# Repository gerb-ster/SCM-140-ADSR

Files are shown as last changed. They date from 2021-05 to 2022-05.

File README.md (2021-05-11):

# SCM 140 ADSR

This module is a straight up clone of the ADSR module found it the famous Roland System-100m modular synthesizer from the ’70’s. It consists of 2 identical ADSR generators with a positive and a negative output. I’ve build this some years ago, there are other simpler designs out there, however, it was a really good learning experience.

## Status: Finished

- done: first schematic & board design
- done: breadboard and test
- done: design frontpanel
- done: order PCB and build prototype

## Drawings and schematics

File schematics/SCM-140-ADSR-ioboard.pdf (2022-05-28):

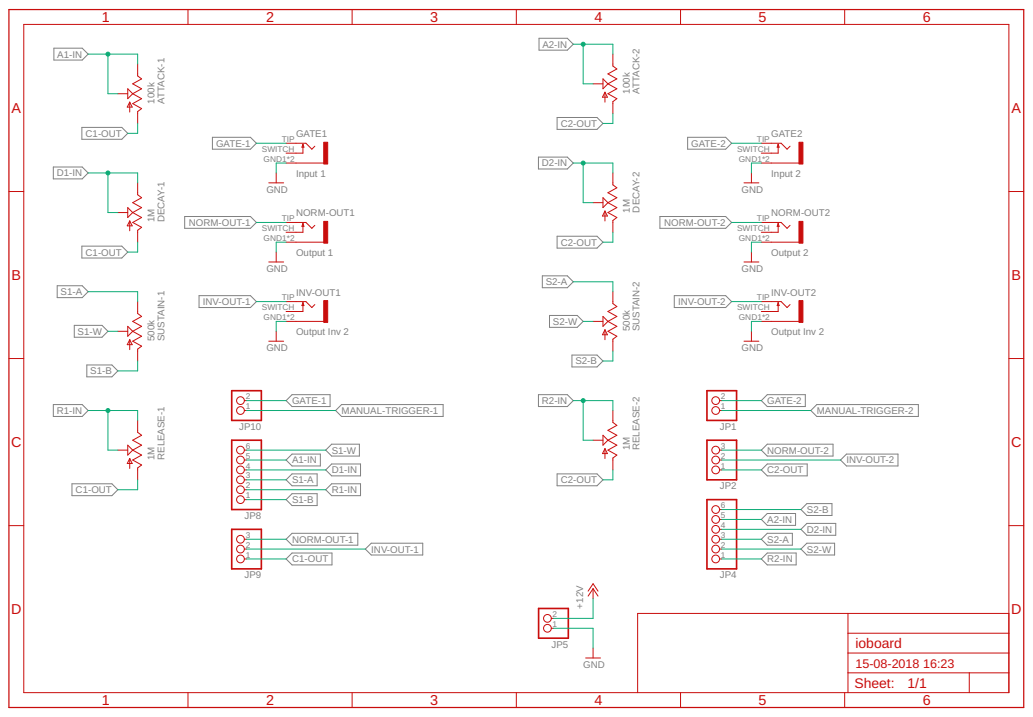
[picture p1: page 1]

100k 1M 500k 1M 100k 1M 500k 1M Input 1 Output 1 Output Inv 2 Input 2 Output 2 Output Inv 2 +12V GND GND GND GND GND GND GND ATTACK-1 DECAY-1 SUSTAIN-1 RELEASE-1 ATTACK-2 DECAY-2 SUSTAIN-2 RELEASE-2 TIP SWITCH GND1*2GATE1 TIP SWITCH GND1*2 NORM-OUT1 TIP SWITCH GND1*2 INV-OUT1 TIP SWITCH GND1*2GATE2 TIP SWITCH GND1*2 NORM-OUT2 TIP SWITCH GND1*2 INV-OUT2 123456JP8 123JP9 12 JP10 123456JP4 12JP1 123JP2 12JP5 MANUAL-TRIGGER-1 S1-B S1-B A1-IN A1-IN S1-W S1-W C1-OUT C1-OUT C1-OUT C1-OUT S1-A S1-A D1-IN D1-IN R1-IN R1-IN GATE-1 GATE-1 NORM-OUT-1 NORM-OUT-1 INV-OUT-1 INV-OUT-1 MANUAL-TRIGGER-2 S2-B S2-B A2-IN A2-IN S2-W S2-W C2-OUT C2-OUT C2-OUT C2-OUT S2-A S2-A R2-IN R2-IN D2-IN D2-IN GATE-2 GATE-2 NORM-OUT-2 NORM-OUT-2 INV-OUT-2 INV-OUT-2 Sheet: ABCD 1 2 3 4 5 6 ABCD 1 2 3 4 5 6 ioboard 15-08-2018 16:23 1/1

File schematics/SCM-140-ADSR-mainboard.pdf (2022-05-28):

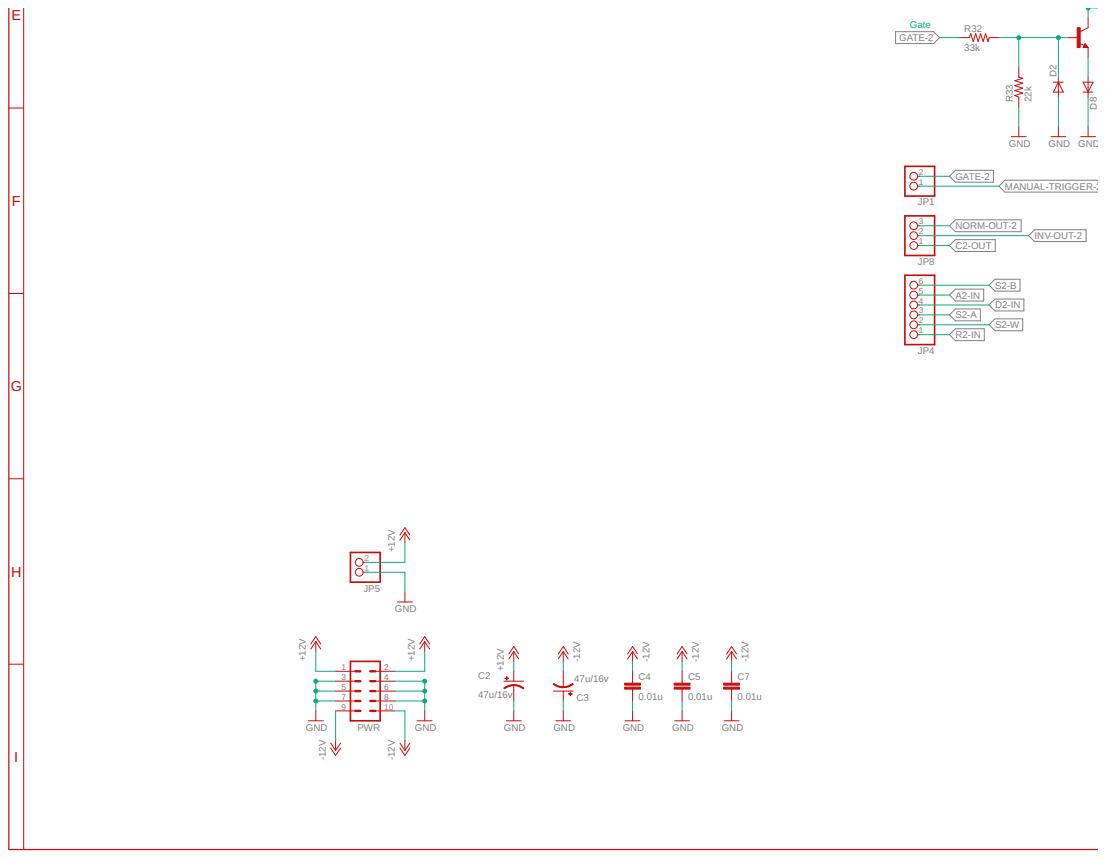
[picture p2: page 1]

-12V -12V GND GND +12V +12V 47u/16v 47u/16v +12V-12V GND GND GND -12V 0.01u 0.01u -12V GND 33k 22k GND GND GND +12V GND 0.01u GND -12V 1 2 3 4 5 6 7 8 9 10 PWR C2 C3 C4 C5 R32 R33 D2 D8 123456JP4 12JP5 12JP1 123JP8 C7 MANUAL-TRIGGER-2 S2-B A2-IN S2-W C2-OUT S2-A R2-IN D2-IN GATE-2 GATE-2 NORM-OUT-2 INV-OUT-2 EFGHI Gate

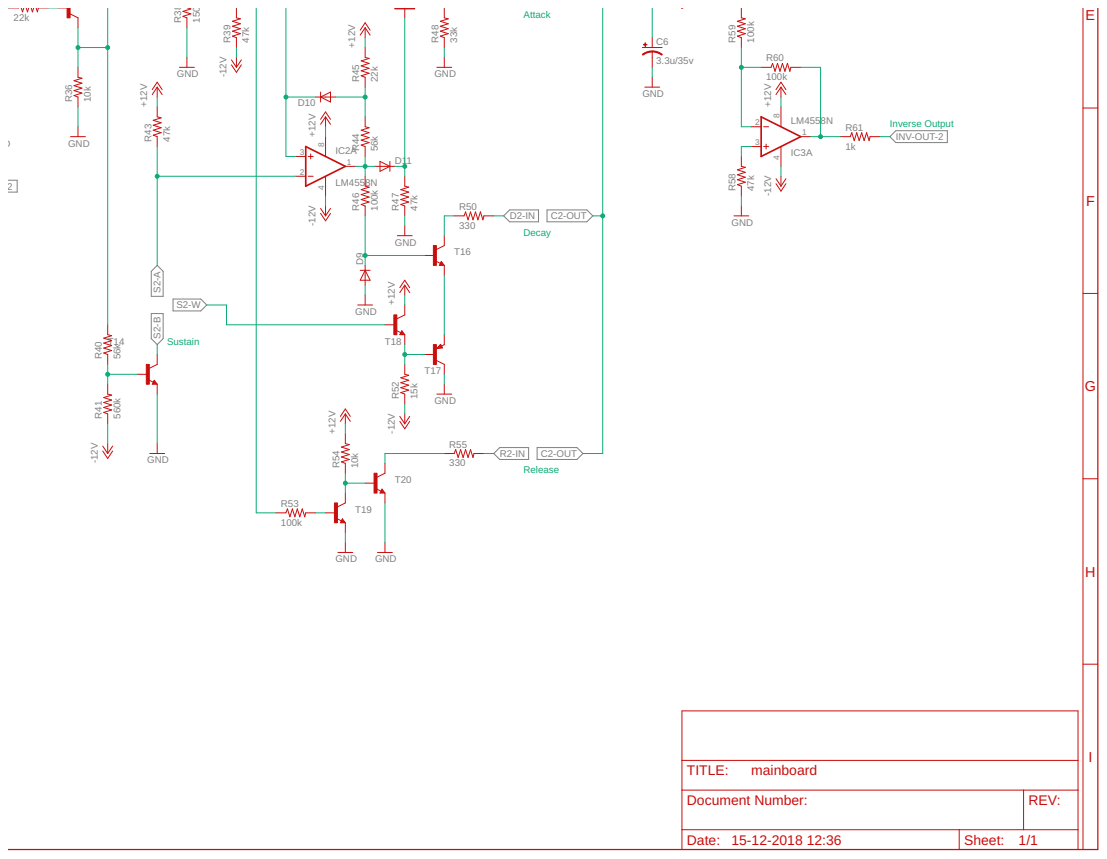
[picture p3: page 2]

Document Number: | REV:

Date: 15-12-2018 12:36 | Sheet: 1/1

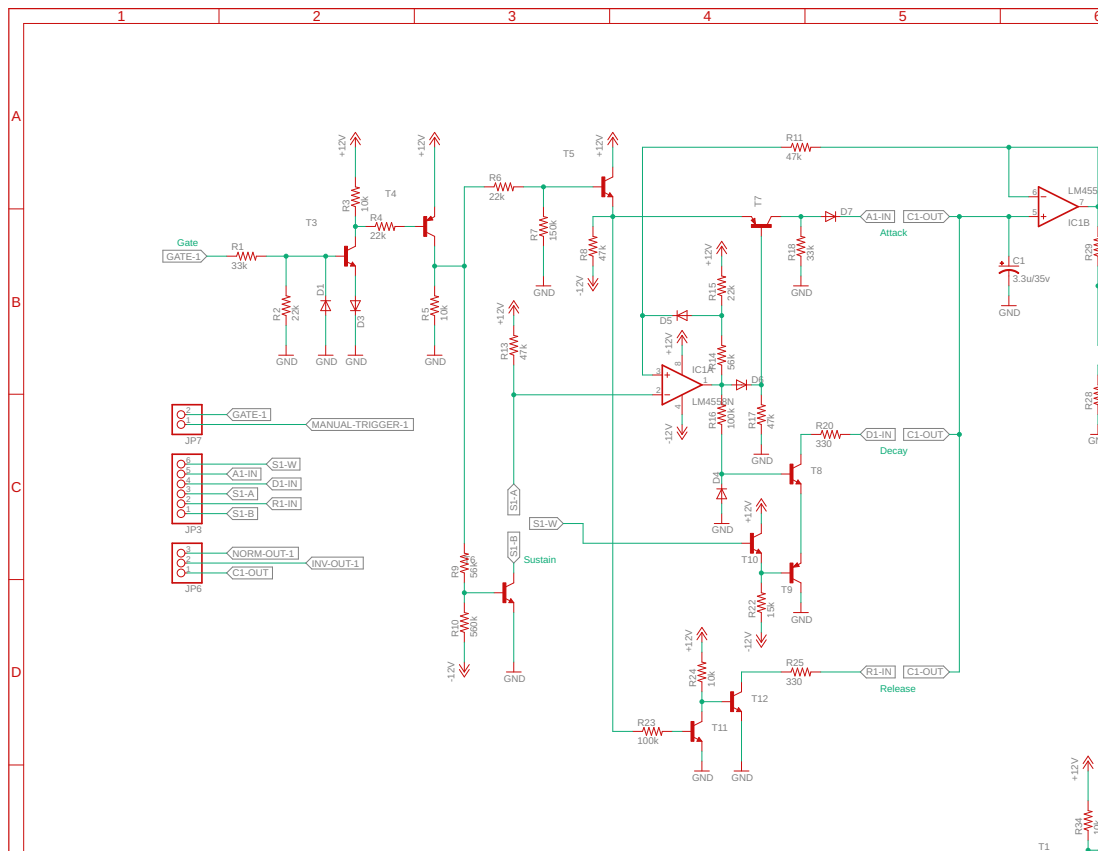
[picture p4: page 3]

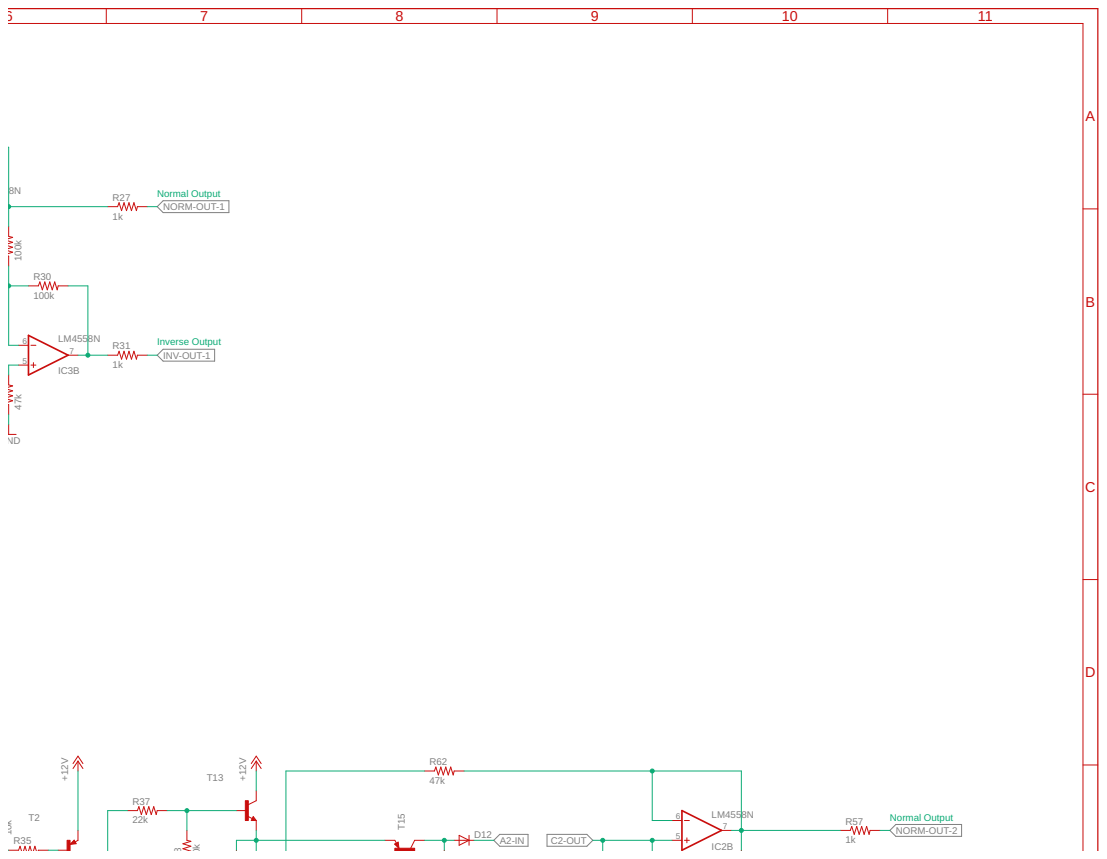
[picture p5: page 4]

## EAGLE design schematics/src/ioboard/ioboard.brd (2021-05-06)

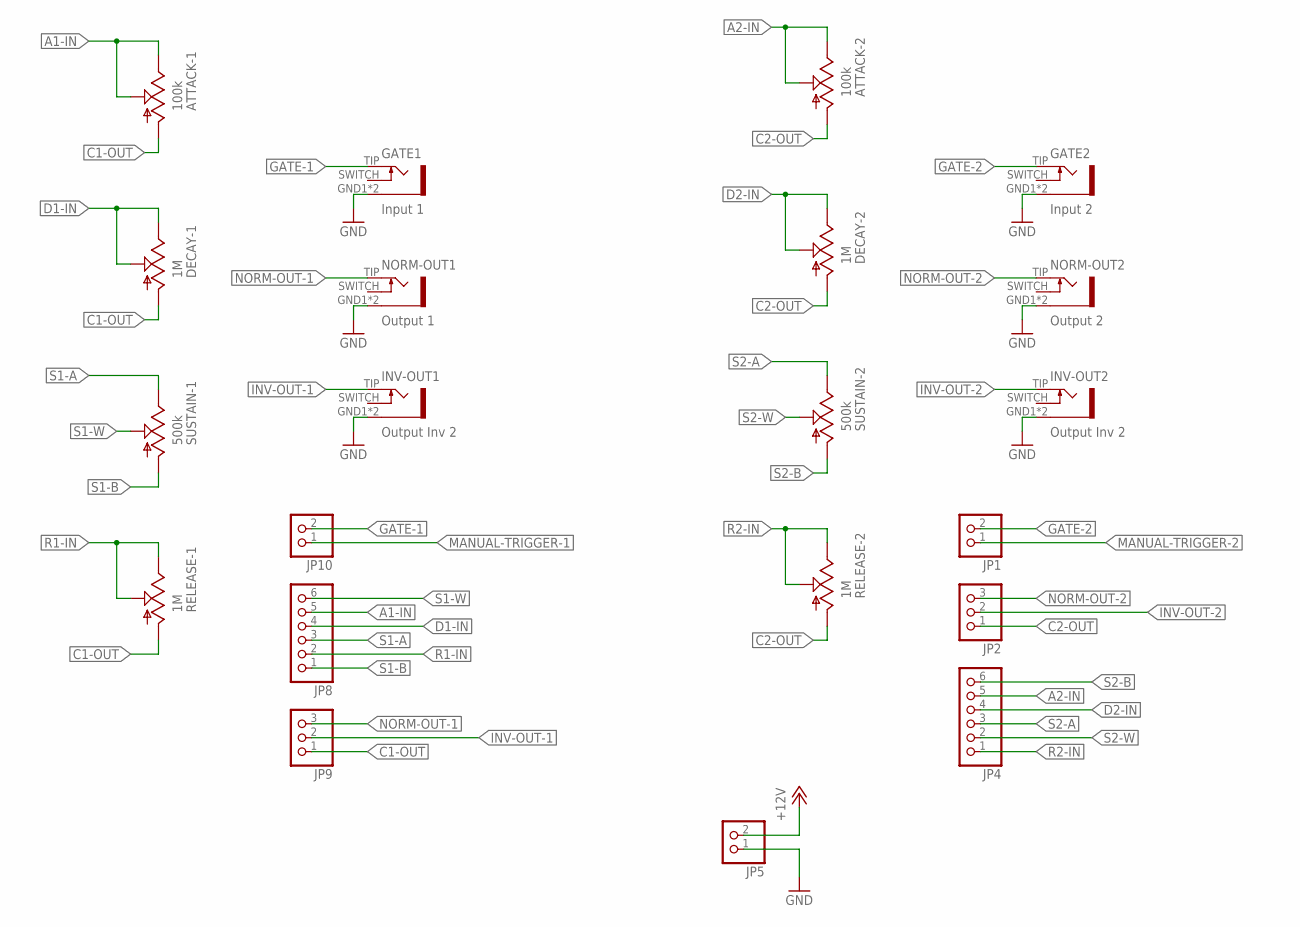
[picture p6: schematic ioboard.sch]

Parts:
ATTACK-1, ATTACK-2: 100k; EVUF
DECAY-1, DECAY-2: 1M; EVUF
GATE1: Input 1; PJ301BM
GATE2: Input 2; PJ301BM
INV-OUT1, INV-OUT2: Output Inv 2; PJ301BM
JP1, JP5, JP10: PINHD-1X2; 1X02
JP2, JP9: PINHD-1X3; 1X03
JP4, JP8: PINHD-1X6; 1X06
NORM-OUT1: Output 1; PJ301BM
NORM-OUT2: Output 2; PJ301BM
RELEASE-1, RELEASE-2: 1M; EVUF
SUSTAIN-1, SUSTAIN-2: 500k; EVUF

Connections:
+12V: JP5.2
A1-IN: ATTACK-1.2 (S), ATTACK-1.3 (E), JP8.5
A2-IN: ATTACK-2.2 (S), ATTACK-2.3 (E), JP4.5
C1-OUT: ATTACK-1.1 (A), DECAY-1.1 (A), JP9.1, RELEASE-1.1 (A)
C2-OUT: ATTACK-2.1 (A), DECAY-2.1 (A), JP2.1, RELEASE-2.1 (A)
D1-IN: DECAY-1.2 (S), DECAY-1.3 (E), JP8.4
D2-IN: DECAY-2.2 (S), DECAY-2.3 (E), JP4.4
GATE-1: GATE1.TIP (3), JP10.2
GATE-2: GATE2.TIP (3), JP1.2
GND: GATE1.GND1 (5), GATE1.GND2 (5), GATE2.GND1 (5), GATE2.GND2 (5), INV-OUT1.GND1 (5), INV-OUT1.GND2 (5), INV-OUT2.GND1 (5), INV-OUT2.GND2 (5), JP5.1, NORM-OUT1.GND1 (5), NORM-OUT1.GND2 (5), NORM-OUT2.GND1 (5), NORM-OUT2.GND2 (5)
INV-OUT-1: INV-OUT1.TIP (3), JP9.2
INV-OUT-2: INV-OUT2.TIP (3), JP2.2
MANUAL-TRIGGER-1: JP10.1
MANUAL-TRIGGER-2: JP1.1
NORM-OUT-1: JP9.3, NORM-OUT1.TIP (3)
NORM-OUT-2: JP2.3, NORM-OUT2.TIP (3)
R1-IN: JP8.2, RELEASE-1.2 (S), RELEASE-1.3 (E)
R2-IN: JP4.1, RELEASE-2.2 (S), RELEASE-2.3 (E)
S1-A: JP8.3, SUSTAIN-1.3 (E)
S1-B: JP8.1, SUSTAIN-1.1 (A)
S1-W: JP8.6, SUSTAIN-1.2 (S)
S2-A: JP4.3, SUSTAIN-2.3 (E)
S2-B: JP4.6, SUSTAIN-2.1 (A)
S2-W: JP4.2, SUSTAIN-2.2 (S)

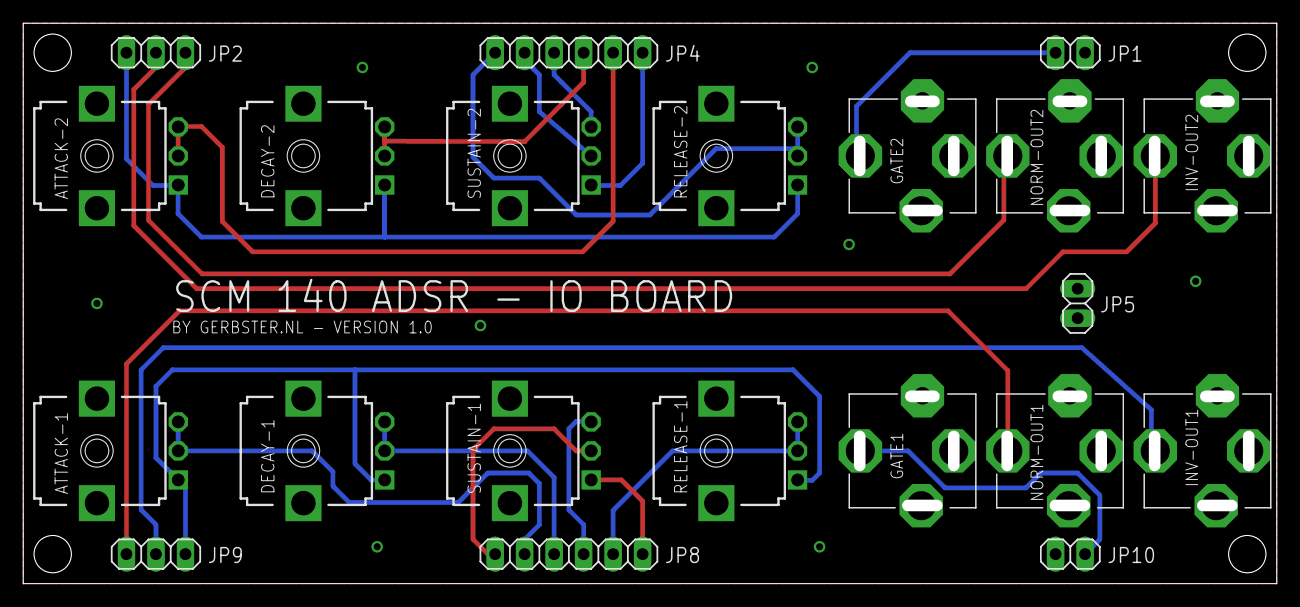
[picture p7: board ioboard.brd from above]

Board: 2 copper layers, 108.0 x 48.3 mm, 21 parts (0 on the bottom side), 21 nets.

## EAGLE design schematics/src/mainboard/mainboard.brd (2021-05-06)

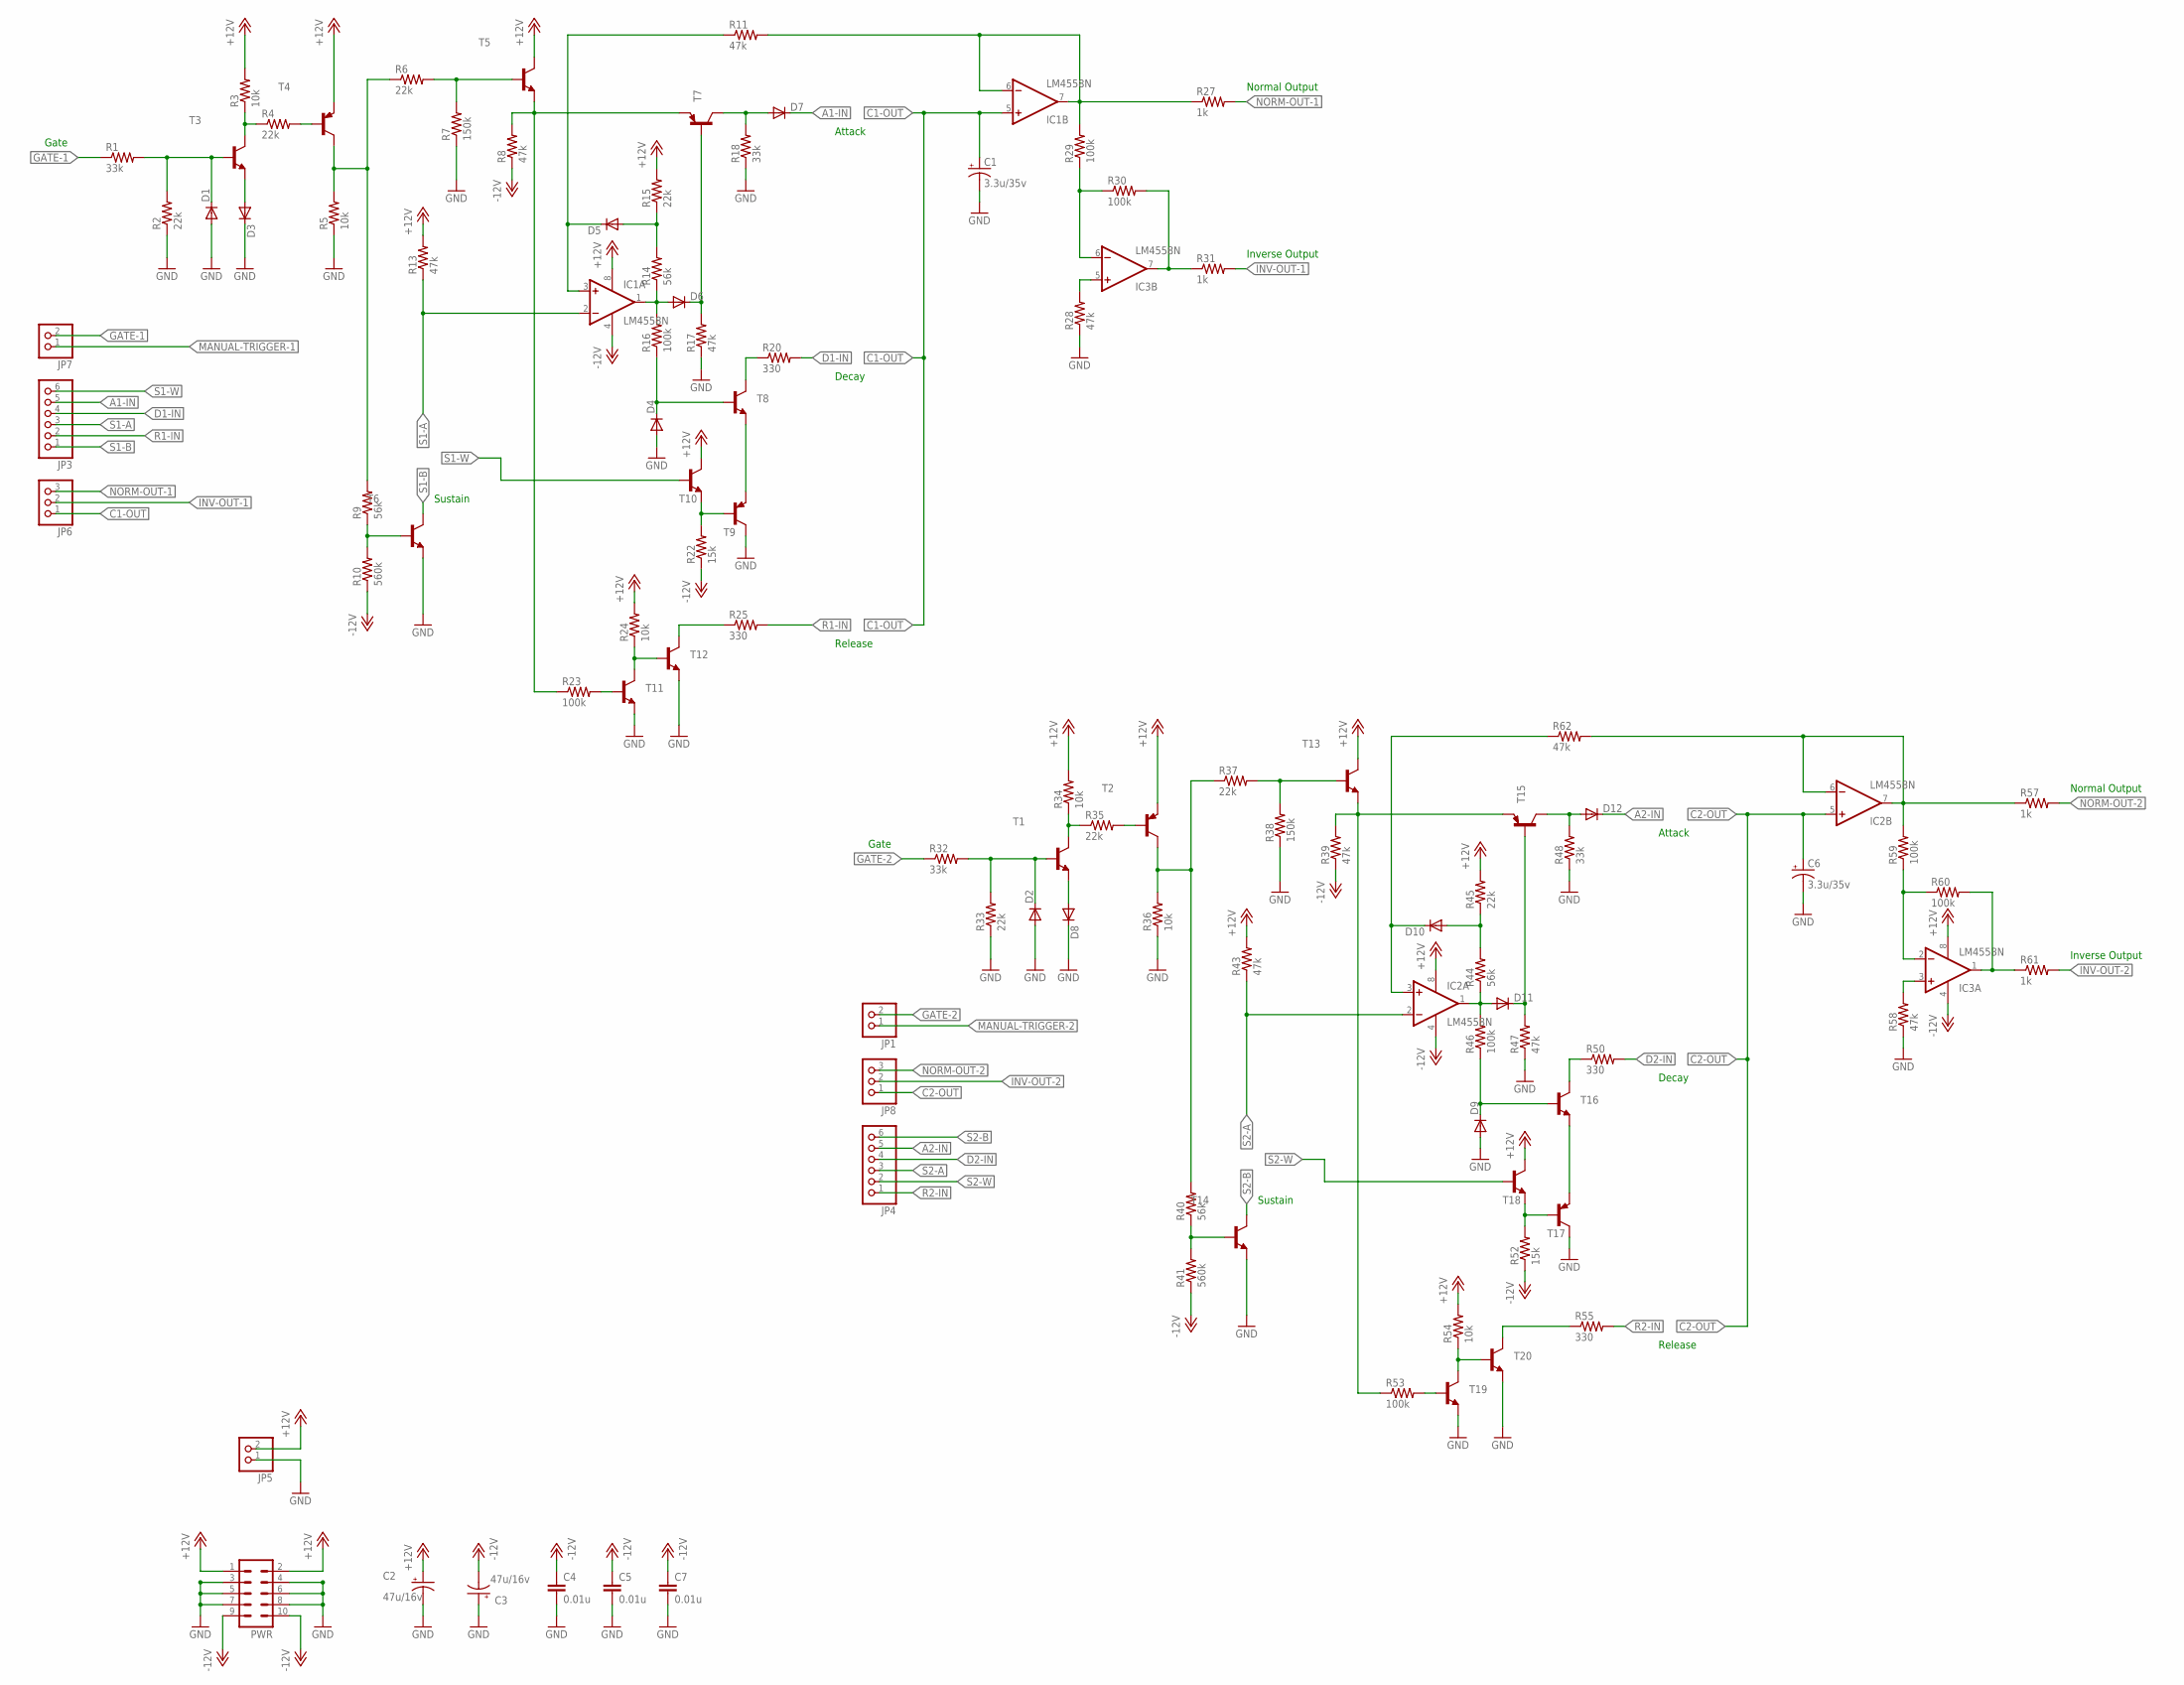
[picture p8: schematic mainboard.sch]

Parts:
C1, C6: 3.3u/35v; E2,5-5
C2, C3: 47u/16v; E2,5-5
C4, C5, C7: 0.01u; C025-024X044
D1, D2, D3, D4, D5, D6, D7, D8, D9, D10, D11, D12: 1N4148DO35-7; DO35-7
IC1, IC2, IC3: LM4558N; DIL08
JP1, JP5, JP7: PINHD-1X2; 1X02
JP3, JP4: PINHD-1X6; 1X06
JP6, JP8: PINHD-1X3; 1X03
PWR: ML10
R1, R18, R32, R48: 33k; 0204/7
R2, R4, R6, R15, R33, R35, R37, R45: 22k; 0204/7
R3, R5, R24, R34, R36, R54: 10k; 0204/7
R7, R38: 150k; 0204/7
R8, R11, R13, R17, R28, R39, R43, R47, R58, R62: 47k; 0204/7
R9, R14, R40, R44: 56k; 0204/7
R10, R41: 560k; 0204/7
R16, R23, R29, R30, R46, R53, R59, R60: 100k; 0204/7
R20, R25, R50, R55: 330; 0204/7
R22, R52: 15k; 0204/7
R27, R31, R57, R61: 1k; 0204/7
T1, T3, T5, T6, T8, T10, T11, T12, T13, T14, T16, T18, T19, T20: BC547B-NPN-TO92-CBE; TO92-CBE
T2, T4, T7, T9, T15, T17: BC557B-PNP-TO92-EBC; TO92-EBC

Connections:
+12V: C2.+, IC1.8 (V+), IC2.8 (V+), IC3.8 (V+), JP5.2, PWR.1, PWR.2, R3.2, R13.2, R15.2, R24.2, R34.2, R43.2, R45.2, R54.2, T2.E, T4.E, T5.C, T10.C, T13.C, T18.C
-12V: C3.-, C4.1, C5.1, C7.1, IC1.4 (V-), IC2.4 (V-), IC3.4 (V-), PWR.9, PWR.10, R8.1, R10.1, R22.1, R39.1, R41.1, R52.1
A1-IN: D7.C, JP3.5
A2-IN: D12.C, JP4.5
C1-OUT: C1.+, IC1.5 (+IN), JP6.1
C2-OUT: C6.+, IC2.5 (+IN), JP8.1
D1-IN: JP3.4, R20.2
D2-IN: JP4.4, R50.2
GATE-1: JP7.2, R1.1
GATE-2: JP1.2, R32.1
GND: C1.-, C2.-, C3.+, C4.2, C5.2, C6.-, C7.2, D1.A, D2.A, D3.C, D4.A, D8.C, D9.A, JP5.1, PWR.3, PWR.4, PWR.5, PWR.6, PWR.7, PWR.8, R2.1, R5.1, R7.1, R17.1, R18.1, R28.1, R33.1, R36.1, R38.1, R47.1, R48.1, R58.1, T6.E, T9.C, T11.E, T12.E, T14.E, T17.C, T19.E, T20.E
INV-OUT-1: JP6.2, R31.2
INV-OUT-2: JP8.2, R61.2
MANUAL-TRIGGER-1: D1.C, JP7.1, R1.2, R2.2, T3.B
MANUAL-TRIGGER-2: D2.C, JP1.1, R32.2, R33.2, T1.B
unnamed: D5.C, IC1.3 (+IN), R11.1
unnamed: D3.A, T3.E
unnamed: R3.1, R4.1, T3.C
unnamed: R4.2, T4.B
unnamed: R5.2, R6.1, R9.2, T4.C
unnamed: R8.2, R23.1, T5.E, T7.E
unnamed: R6.2, R7.2, T5.B
unnamed: R9.1, R10.2, T6.B
unnamed: D6.A, IC1.1 (OUT), R14.1, R16.2
unnamed: D4.C, R16.1, T8.B
unnamed: D5.A, R14.2, R15.1
unnamed: IC1.6 (-IN), IC1.7 (OUT), R11.2, R27.1, R29.2
unnamed: D7.A, R18.2, T7.C
unnamed: D6.C, R17.2, T7.B
unnamed: IC3.6 (-IN), R29.1, R30.1
unnamed: R20.1, T8.C
unnamed: R22.2, T9.B, T10.E
unnamed: T8.E, T9.E
unnamed: R23.2, T11.B
unnamed: R24.1, T11.C, T12.B
unnamed: R25.1, T12.C
unnamed: IC3.7 (OUT), R30.2, R31.1
unnamed: D8.A, T1.E
unnamed: IC3.5 (+IN), R28.2
unnamed: R34.1, R35.1, T1.C
unnamed: R35.2, T2.B
unnamed: R36.2, R37.1, R40.2, T2.C
unnamed: R39.2, R53.1, T13.E, T15.E
unnamed: R37.2, R38.2, T13.B
unnamed: R40.1, R41.2, T14.B
unnamed: D11.A, IC2.1 (OUT), R44.1, R46.2
unnamed: D9.C, R46.1, T16.B
unnamed: D10.A, R44.2, R45.1
unnamed: IC2.6 (-IN), IC2.7 (OUT), R57.1, R59.2, R62.2
unnamed: D11.C, R47.2, T15.B
unnamed: D12.A, R48.2, T15.C
unnamed: R50.1, T16.C
unnamed: R52.2, T17.B, T18.E
unnamed: T16.E, T17.E
unnamed: R53.2, T19.B
unnamed: R54.1, T19.C, T20.B
unnamed: R55.1, T20.C
unnamed: IC3.2 (-IN), R59.1, R60.1
unnamed: IC3.1 (OUT), R60.2, R61.1
unnamed: IC3.3 (+IN), R58.2
unnamed: D10.C, IC2.3 (+IN), R62.1
NORM-OUT-1: JP6.3, R27.2
NORM-OUT-2: JP8.3, R57.2
R1-IN: JP3.2, R25.2
R2-IN: JP4.1, R55.2
S1-A: IC1.2 (-IN), JP3.3, R13.1
S1-B: JP3.1, T6.C
S1-W: JP3.6, T10.B
S2-A: IC2.2 (-IN), JP4.3, R43.1
S2-B: JP4.6, T14.C
S2-W: JP4.2, T18.B

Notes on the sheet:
Attack
Decay
Release
Sustain
Gate
Normal Output
Inverse Output

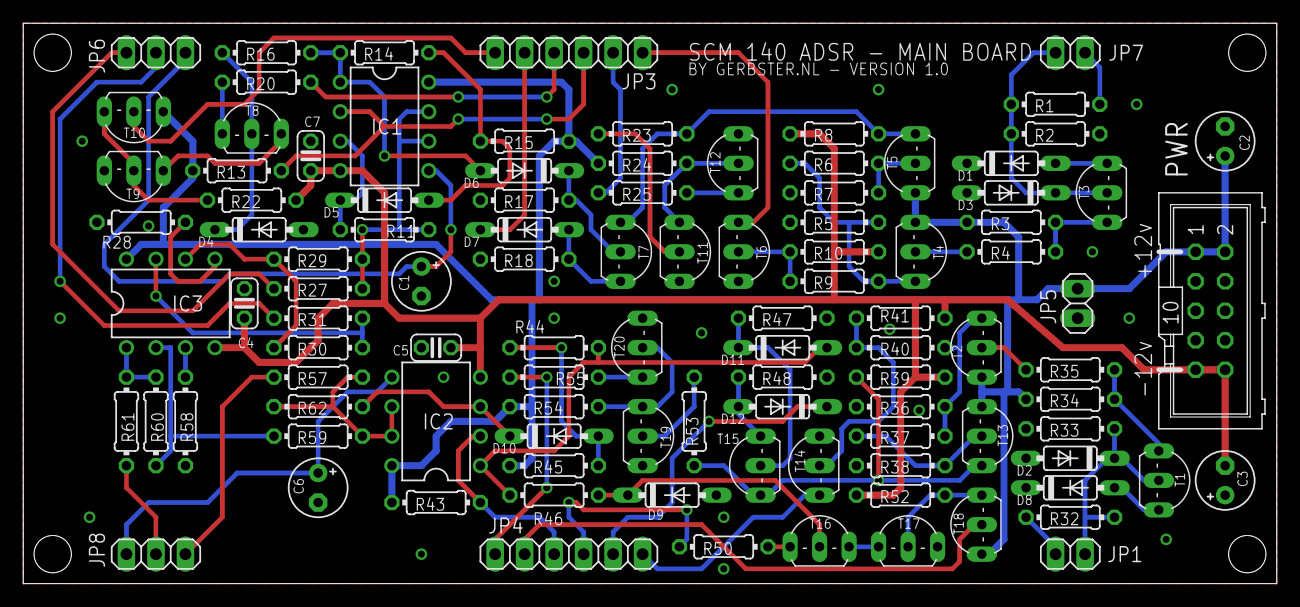
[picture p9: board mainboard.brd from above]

Board: 2 copper layers, 108.0 x 48.3 mm, 104 parts (0 on the bottom side), 71 nets.

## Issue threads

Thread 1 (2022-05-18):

LM4558B or TL072?

KeLaiFu, 2022-05-18:
The BOM states LM4558B opamps, but the layout would indicate that standard TL072 should be used, unless I am misunderstanding something?

gerb-ster, 2022-05-18:
I didn't have a LM4558 opamp in my EagleCad library and since it has the same footprint as a TL072 I've used that one. The original design uses LM4558's, however they are interchangeable, should you not be able to find them.

Closed 2022-05-18.

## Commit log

2021-05-06 some files
    [SCM-140-ADSR-IO.brd, SCM-140-ADSR-IO.sch, SCM-140-ADSR.brd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]
2021-05-07 Added files & structure
    [SCM-140-ADSR-ioboard.GBL, SCM-140-ADSR-ioboard.GBO, SCM-140-ADSR-ioboard.GBP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]
2021-08-06 Updated some schematics and docs
    [SCM-140-ADSR-ioboard.GBL, SCM-140-ADSR-ioboard.GBO, SCM-140-ADSR-ioboard.GBP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]
2021-08-10 Fixed some bugs and updated documentation
    [SCM-140-ADSR-ioboard.XLN, SCM-140-ADSR-mainboard.XLN, gerber_job.gbrjob]
2022-04-20 Some updates & bugfixes
    [SCM-140-ADSR-ioboard.XLN, SCM-140-ADSR-mainboard.XLN, gerber_job.gbrjob]
2022-04-22 Fixed schematics & descriptions
    [SCM-140-ADSR-ioboard.XLN, SCM-140-ADSR-mainboard.XLN, gerber_job.gbrjob]
2022-05-17 Updated Firmware
    [SCM-140-ADSR-ioboard.XLN, SCM-140-ADSR-mainboard.XLN, gerber_job.gbrjob]
2022-05-18 Updated Faceplates
    [SCM-140-ADSR-ioboard.XLN, SCM-140-ADSR-mainboard.XLN, gerber_job.gbrjob]
2022-05-18 Fixed issues
    [SCM-140-ADSR-ioboard.XLN, SCM-140-ADSR-mainboard.XLN, gerber_job.gbrjob]
2022-05-21 Fixed schematics
    [SCM-140-ADSR-ioboard.XLN, SCM-140-ADSR-mainboard.XLN, gerber_job.gbrjob]
2022-05-28 General updates
    [SCM-140-ADSR-ioboard.GKO, SCM-140-ADSR-mainboard.GKO, copper_bottom.gbr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]
